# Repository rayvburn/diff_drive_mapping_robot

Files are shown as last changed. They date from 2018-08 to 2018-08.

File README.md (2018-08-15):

# diff_drive_mapping_robot
This is the ROS driver for the Raspberry Pi based differential drive robot that was built as a part of my MSc thesis. 

Base of the robot was made of acrylic glass. The locomotion is provided by 3 wheels, including 1 caster. The two-wheel differential drive based on DC motors makes the machine nonholonomic.

Within the electronic part of the robot's construction, a printed circuit board was designed. All the necessary electronical components including reflective sensors used to measure the distance from obstacles were placed on the board. The sensor providing the largest amount of data is the camera. It is integrated with the Raspberry Pi microcomputer. The extension of the microcomputer's tasks to the reading of wheel positions and motor control allowed to use its resources efficiently and to avoid adding an extra microcontroller.

Looking at the PCB project (made in KiCad) should give you some idea what components to use if you plan to make a copy of it.

The robot is intended to work together with remote machine like PC that performs some more sophisticated duties. It was created to interface with ORB-SLAM2 well.

# Installation instructions

The package contents should be placed and compiled both on PC and on RPi's SD card. It was tested only on ROS Kinetic (running on Ubuntu 16.04).

wiringPi library is needed (http://wiringpi.com/). A script to install it on Raspberry Pi was provided.

raspicam_node (https://github.com/UbiquityRobotics/raspicam_node) is required if you will use Raspberry Pi camera but isn't marked as dependency for the package. If you don't plan to use it, just remove appropriate line in robot/robot_offline .launch file (the one with inclusion of raspicam_node's .launch).

# Usage

If a Raspberry Pi is present within a local Wi-Fi network

    roslaunch diff_drive_mapping_robot robot.launch

or for testing purposes (no RPi)

    roslaunch diff_drive_mapping_robot robot_offline.launch
    
# Notes
I highly recommend acquiring an Ubuntu image adequate for Raspberry Pi (with ROS Kinetic already installed) from here: https://downloads.ubiquityrobotics.com/pi.html

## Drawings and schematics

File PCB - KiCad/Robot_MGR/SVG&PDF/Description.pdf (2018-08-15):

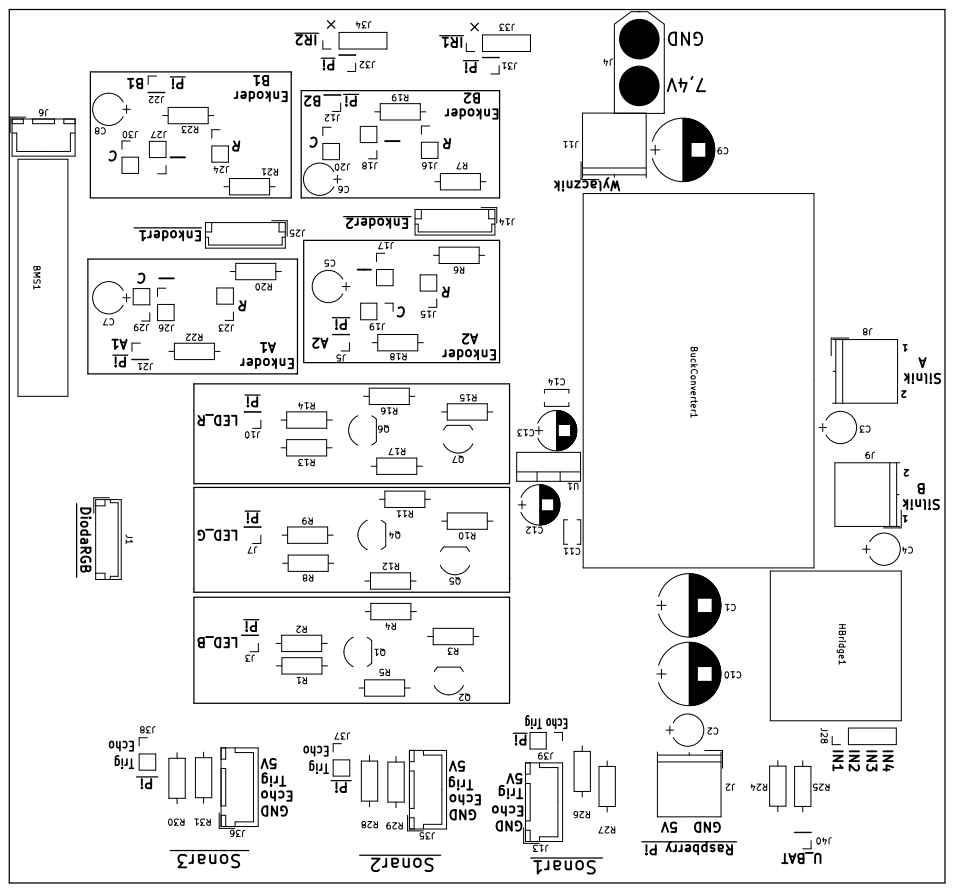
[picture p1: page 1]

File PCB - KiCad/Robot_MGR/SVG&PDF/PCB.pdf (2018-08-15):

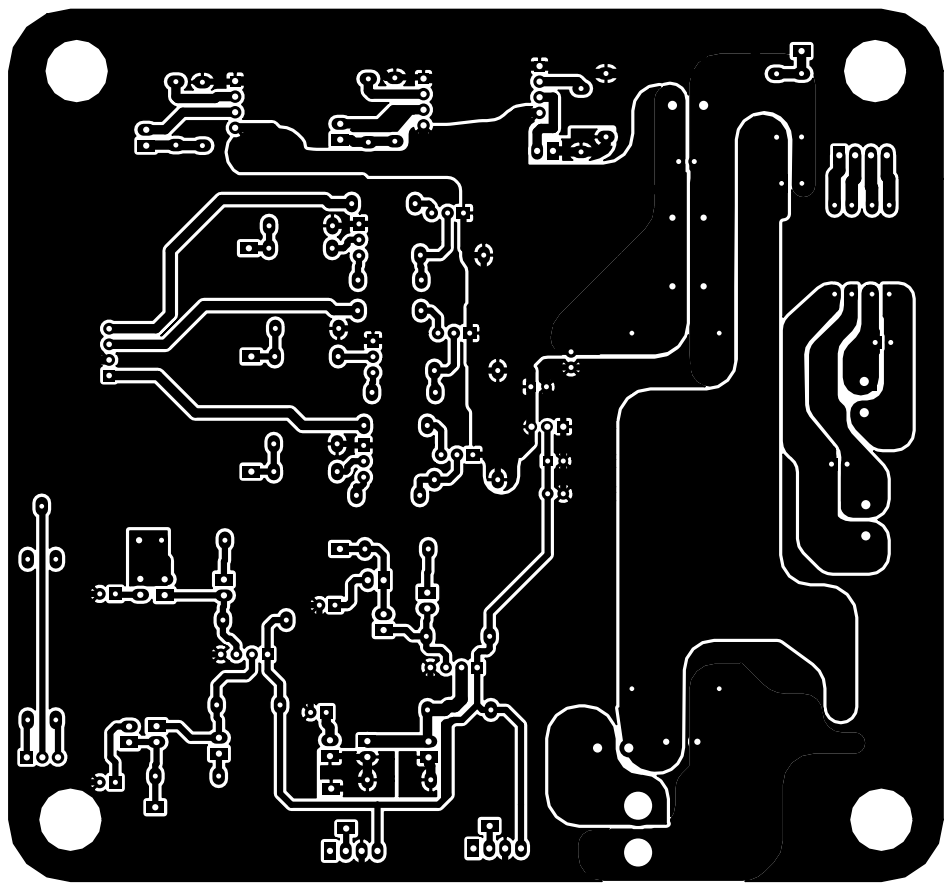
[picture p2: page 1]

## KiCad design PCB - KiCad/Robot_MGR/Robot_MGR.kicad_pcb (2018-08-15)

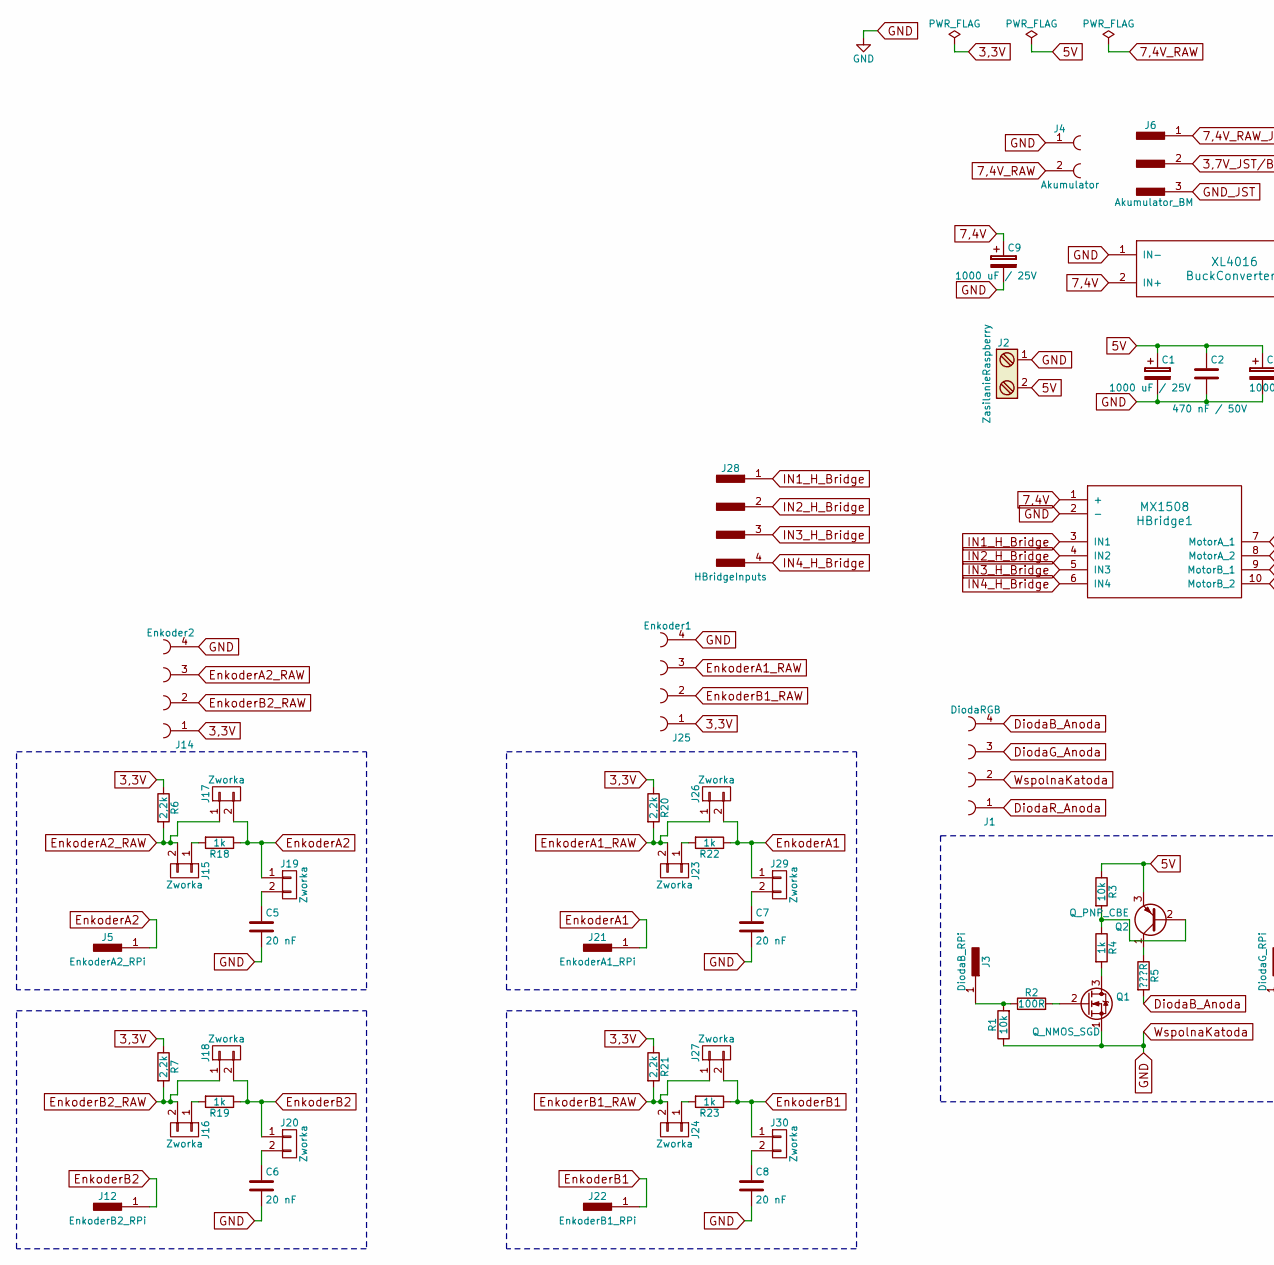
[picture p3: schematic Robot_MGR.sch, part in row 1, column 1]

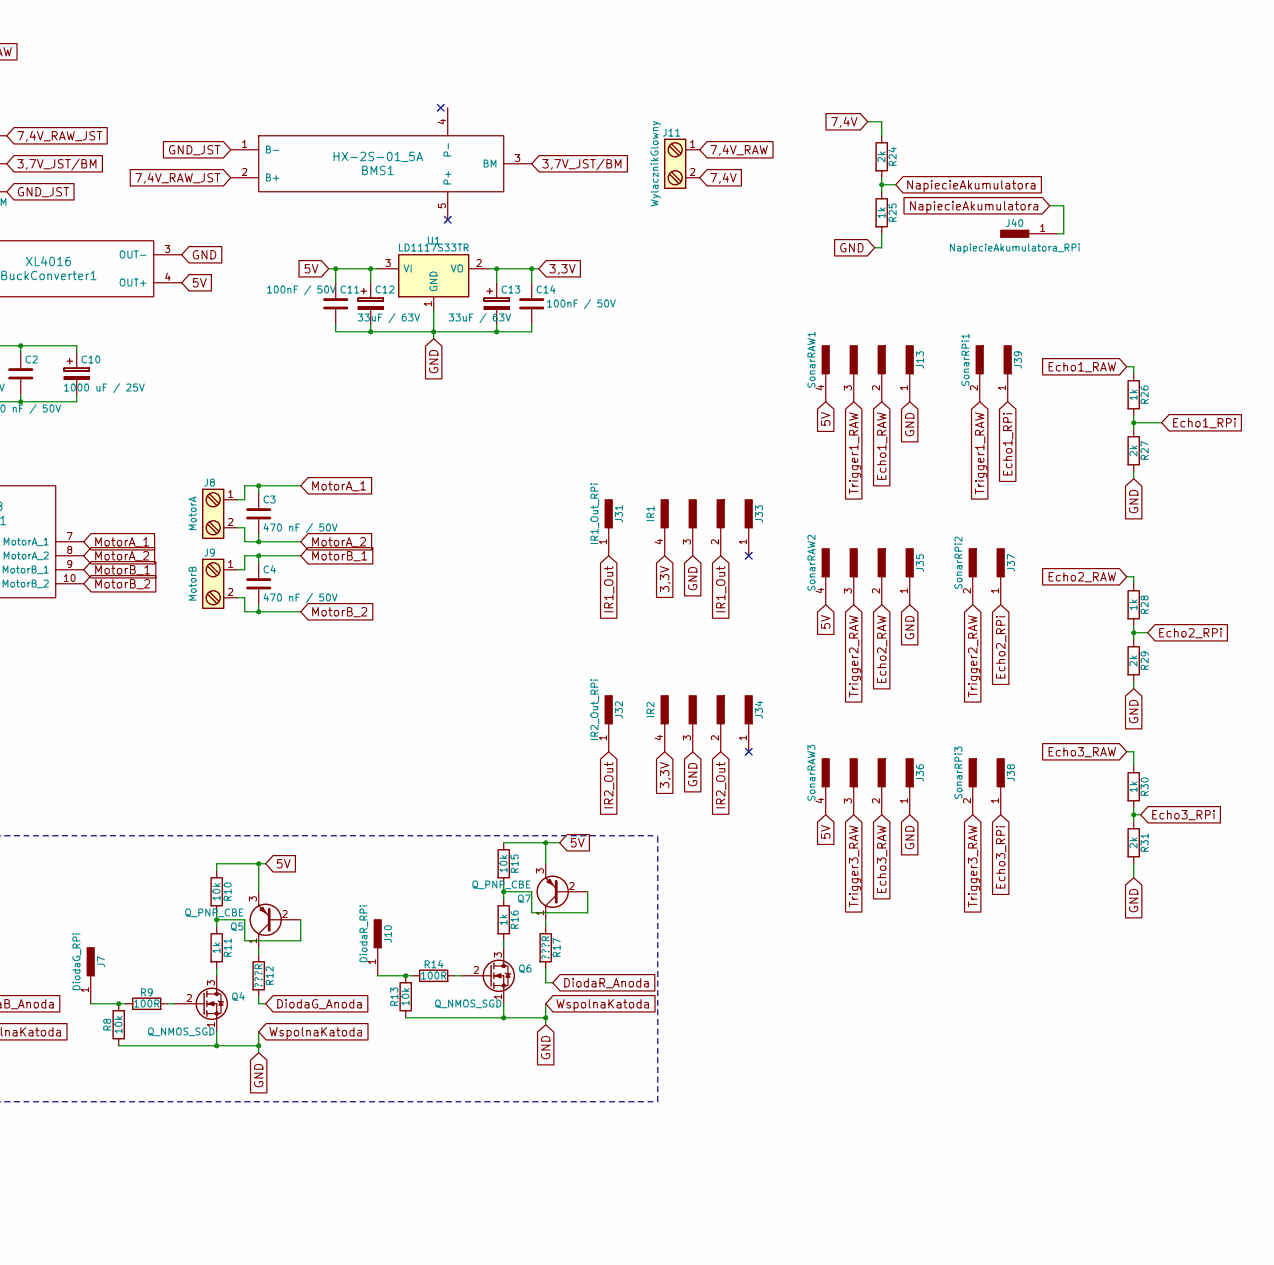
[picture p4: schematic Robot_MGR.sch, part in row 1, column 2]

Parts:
BMS1: HX-2S-01_5A
BuckConverter1: XL4016
C1, C9, C10: 1000 uF / 25V; CP_Radial_D10.0mm_P5.00mm
C2, C3, C4: 470 nF / 50V; CP_Radial_Tantal_D5.0mm_P2.50mm
C5, C6, C7, C8: 20 nF; CP_Radial_Tantal_D5.0mm_P2.50mm
C11, C14: 100nF / 50V; C_Disc_D3.8mm_W2.6mm_P2.50mm
C12, C13: 33uF / 63V; CP_Radial_D6.3mm_P2.50mm
HBridge1: MX1508
J1: DiodaRGB; JST_EH_B04B-EH-A_04x2.50mm_Straight
J2: ZasilanieRaspberry; TerminalBlock_Philmore_TB132_02x5mm_Straight
J3: DiodaB_RPi; Pin_Header_Straight_1x01_Pitch2.54mm
J4: Akumulator; XT60
J5: EnkoderA2_RPi; Pin_Header_Straight_1x01_Pitch2.54mm
J6: Akumulator_BM; JST_XH_B03B-XH-A_03x2.50mm_Straight
J7: DiodaG_RPi; Pin_Header_Straight_1x01_Pitch2.54mm
J8: MotorA; TerminalBlock_Philmore_TB132_02x5mm_Straight
J9: MotorB; TerminalBlock_Philmore_TB132_02x5mm_Straight
J10: DiodaR_RPi; Pin_Header_Straight_1x01_Pitch2.54mm
J11: WylacznikGlowny; TerminalBlock_Philmore_TB132_02x5mm_Straight
J12: EnkoderB2_RPi; Pin_Header_Straight_1x01_Pitch2.54mm
J13: SonarRAW1; JST_XH_B04B-XH-A_04x2.50mm_Straight
J14: Enkoder2; JST_EH_B04B-EH-A_04x2.50mm_Straight
J15, J16, J17, J18, J19, J20, J23, J24, J26, J27, J29, J30: Zworka; Pin_Header_Straight_1x02_Pitch2.54mm
J21: EnkoderA1_RPi; Pin_Header_Straight_1x01_Pitch2.54mm
J22: EnkoderB1_RPi; Pin_Header_Straight_1x01_Pitch2.54mm
J25: Enkoder1; JST_EH_B04B-EH-A_04x2.50mm_Straight
J28: HBridgeInputs; Pin_Header_Straight_1x04_Pitch2.54mm
J31: IR1_Out_RPi; Pin_Header_Straight_1x01_Pitch2.54mm
J32: IR2_Out_RPi; Pin_Header_Straight_1x01_Pitch2.54mm
J33: IR1; Pin_Header_Straight_1x04_Pitch2.54mm
J34: IR2; Pin_Header_Straight_1x04_Pitch2.54mm
J35: SonarRAW2; JST_XH_B04B-XH-A_04x2.50mm_Straight
J36: SonarRAW3; JST_XH_B04B-XH-A_04x2.50mm_Straight
J37: SonarRPi2; Pin_Header_Straight_1x02_Pitch2.54mm
J38: SonarRPi3; Pin_Header_Straight_1x02_Pitch2.54mm
J39: SonarRPi1; Pin_Header_Straight_1x02_Pitch2.54mm
J40: NapiecieAkumulatora_RPi; Pin_Header_Straight_1x01_Pitch2.54mm
Q1, Q4, Q6: Q_NMOS_SGD; TO-92_Inline_Wide
Q2, Q5, Q7: Q_PNP_CBE; TO-92_Inline_Wide
R1, R3, R8, R10, R13, R15: 10k; R_Axial_DIN0207_L6.3mm_D2.5mm_P10.16mm_Horizontal
R2, R9, R14: 100R; R_Axial_DIN0207_L6.3mm_D2.5mm_P10.16mm_Horizontal
R4, R11, R16, R18, R19, R22, R23, R25, R26, R28, R30: 1k; R_Axial_DIN0207_L6.3mm_D2.5mm_P10.16mm_Horizontal
R5, R12, R17: ???R; R_Axial_DIN0207_L6.3mm_D2.5mm_P10.16mm_Horizontal
R6, R7, R20, R21: 2,2k; R_Axial_DIN0207_L6.3mm_D2.5mm_P10.16mm_Horizontal
R24, R27, R29, R31: 2k; R_Axial_DIN0207_L6.3mm_D2.5mm_P10.16mm_Horizontal
U1: LD1117S33TR; TO-220-3_Vertical

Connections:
3,3V: C13.1, C14.1, J14.1, J25.1, J33.4, J34.4, R6.1, R7.1, R20.1, R21.1, U1.2 (VO)
3,7V_JST/BM: BMS1.3 (BM), J6.2
5V: BuckConverter1.4 (OUT+), C1.1, C2.1, C10.1, C11.1, C12.1, J2.2, J13.4, J35.4, J36.4, Q2.3 (E), Q5.3 (E), Q7.3 (E), R3.1, R10.1, R15.1, U1.3 (VI)
7,4V: BuckConverter1.2 (IN+), C9.1, HBridge1.1 (+), J11.2, R24.1
7,4V_RAW: J4.2, J11.1
7,4V_RAW_JST: BMS1.2 (B+), J6.1
DiodaB_Anoda: J1.4, R5.2
DiodaG_Anoda: J1.3, R12.2
DiodaR_Anoda: J1.1, R17.2
Echo1_RAW: J13.2, R26.1
Echo1_RPi: J39.1, R26.2, R27.1
Echo2_RAW: J35.2, R28.1
Echo2_RPi: J37.1, R28.2, R29.1
Echo3_RAW: J36.2, R30.1
Echo3_RPi: J38.1, R30.2, R31.1
EnkoderA1: J21.1, J26.2, J29.1, R22.1
EnkoderA1_RAW: J23.2, J25.3, J26.1, R20.2
EnkoderA2: J5.1, J17.2, J19.1, R18.1
EnkoderA2_RAW: J14.3, J15.2, J17.1, R6.2
EnkoderB1: J22.1, J27.2, J30.1, R23.1
EnkoderB1_RAW: J24.2, J25.2, J27.1, R21.2
EnkoderB2: J12.1, J18.2, J20.1, R19.1
EnkoderB2_RAW: J14.2, J16.2, J18.1, R7.2
GND: BuckConverter1.1 (IN-), BuckConverter1.3 (OUT-), C1.2, C2.2, C5.2, C6.2, C7.2, C8.2, C9.2, C10.2, C11.2, C12.2, C13.2, C14.2, HBridge1.2 (-), J1.2, J2.1, J4.1, J13.1, J14.4, J25.4, J33.3, J34.3, J35.1, J36.1, Q1.1 (S), Q4.1 (S), Q6.1 (S), R1.1, R8.1, R13.1, R25.2, R27.2, R29.2, R31.2, U1.1 (GND)
GND_JST: BMS1.1 (B-), J6.3
IN1_H_Bridge: HBridge1.3 (IN1), J28.1
IN2_H_Bridge: HBridge1.4 (IN2), J28.2
IN3_H_Bridge: HBridge1.5 (IN3), J28.3
IN4_H_Bridge: HBridge1.6 (IN4), J28.4
IR1_Out: J31.1, J33.2
IR2_Out: J32.1, J34.2
MotorA_1: C3.1, HBridge1.7 (MotorA_1), J8.1
MotorA_2: C3.2, HBridge1.8 (MotorA_2), J8.2
MotorB_1: C4.1, HBridge1.9 (MotorB_1), J9.1
MotorB_2: C4.2, HBridge1.10 (MotorB_2), J9.2
NapiecieAkumulatora: J40.1, R24.2, R25.1
unnamed: C5.1, J19.2
unnamed: C6.1, J20.2
unnamed: C7.1, J29.2
unnamed: C8.1, J30.2
unnamed: J3.1, R1.2, R2.1
unnamed: J7.1, R8.2, R9.1
unnamed: J10.1, R13.2, R14.1
unnamed: J15.1, R18.2
unnamed: J16.1, R19.2
unnamed: J23.1, R22.2
unnamed: J24.1, R23.2
unnamed: Q1.2 (G), R2.2
unnamed: Q1.3 (D), R4.2
unnamed: Q2.1 (C), R5.1
unnamed: Q2.2 (B), R3.2, R4.1
unnamed: Q4.2 (G), R9.2
unnamed: Q4.3 (D), R11.2
unnamed: Q5.1 (C), R12.1
unnamed: Q5.2 (B), R10.2, R11.1
unnamed: Q6.2 (G), R14.2
unnamed: Q6.3 (D), R16.2
unnamed: Q7.1 (C), R17.1
unnamed: Q7.2 (B), R15.2, R16.1
Trigger1_RAW: J13.3, J39.2
Trigger2_RAW: J35.3, J37.2
Trigger3_RAW: J36.3, J38.2

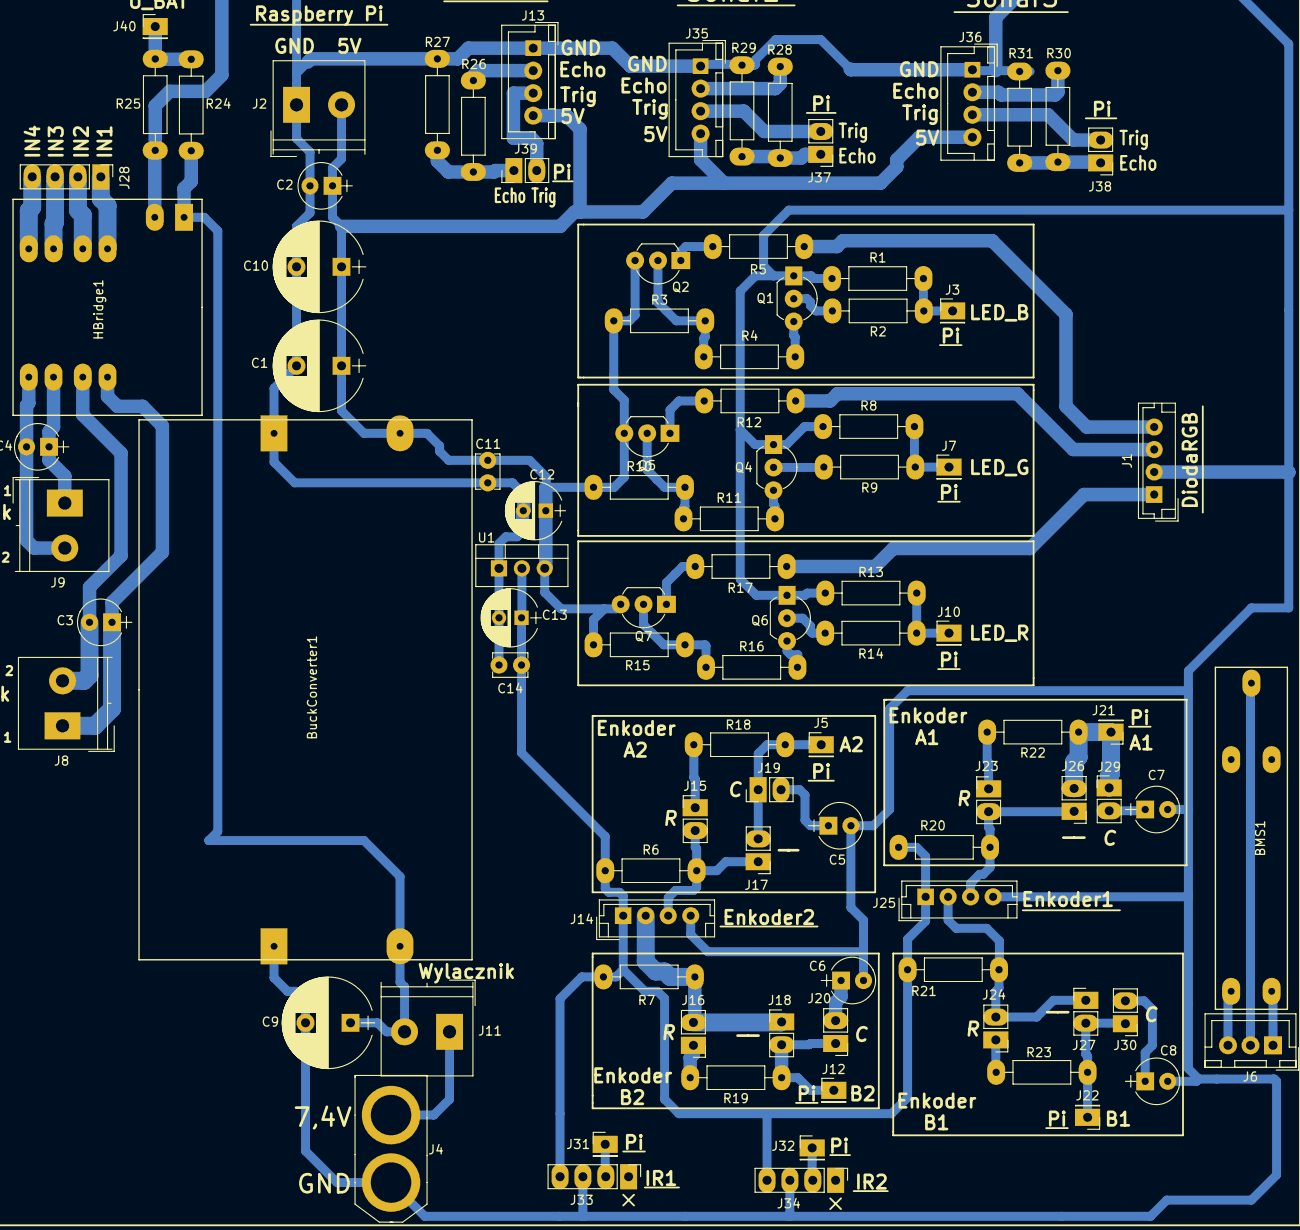
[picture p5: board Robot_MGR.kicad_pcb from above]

Board: 2 copper layers, 95 parts (0 on the bottom side), 62 nets.

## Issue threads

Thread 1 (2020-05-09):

Tuning PID controllers

f-jiang, 2020-05-09:
I'm not sure if this is the right place to be asking, but I have a robot similar to yours with the `diff_drive_controller` and `pid` nodes organized the exact same way. I'm currently at the stage of tuning my PID controllers and wanted to understand the best approach to doing so. Did you tune your PIDs in a simulator, and how did you set things up?

rayvburn, 2020-07-29:
Sorry for a late reply.

Whole testing process was conducted on the real robot. To tune the PID params I used a trial and error method, starting from a set of verified settings from some example.

Closed 2020-07-29.

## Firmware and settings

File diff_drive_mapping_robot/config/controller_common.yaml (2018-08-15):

mobile_base_controller:
  enable_odom_tf: true
  odom_frame_id: odom
  publish_cmd: true
  angular:
    z: {has_acceleration_limits: true, has_jerk_limits: true, has_velocity_limits: true,
      max_acceleration: 2.5, max_jerk: 5.0, max_velocity: 25.0}
  base_frame_id: base_link
  cmd_vel_timeout: 1.15 # needed to be higher due to some networks lags, was 0.25
  left_wheel: wheel_0_joint
  linear:
    x: {has_acceleration_limits: true, has_jerk_limits: true, has_velocity_limits: true,
      max_acceleration: 1.0, max_jerk: 5.0, max_velocity: 25.0, min_acceleration: -1.0,
      min_velocity: -25.0}
  pose_covariance_diagonal: [0.001, 0.001, 1000000.0, 1000000.0, 1000000.0, 1000.0]
  publish_rate: 25.0 # 100.0
  right_wheel: wheel_1_joint
  twist_covariance_diagonal: [0.001, 0.001, 1000000.0, 1000000.0, 1000000.0, 1000.0]
  type: diff_drive_controller/DiffDriveController
  wheel_radius: 0.03315
  wheel_radius_multiplier: 1.0
  wheel_separation: 0.1655
  wheel_separation_multiplier: 1.0

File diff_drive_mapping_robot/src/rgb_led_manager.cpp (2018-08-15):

/*
 * rgb_led_manager.cpp
 *
 *  Created on: Apr 11, 2018
 *      Author: jarek
 */

#include <ros/ros.h>
#include <ros/callback_queue.h>
#include <softPwm.h>
#include <wiringPi.h>
#include <sensor_msgs/BatteryState.h>
#include <std_msgs/Bool.h>
#include <std_msgs/String.h>

#define LED_RED_PIN             3
#define LED_GREEN_PIN           2
#define LED_BLUE_PIN            0

#define MAX_PWM_VALUE         100
#define SINGLE_LED_PWM_VALUE   20

#define EVENT_DURATION         10

static float intensity_factor;
static float blinking_frequency;

static uint8_t slam_state = 5;     // ORB description
static bool loop_detected = false; // GBA is running
static bool loop_blinking = false; // to prevent switching _detected to false when GBA is finished

// prototypes
void colorsInitialization();
struct RGBColor;
void lightUp(const RGBColor *color);

struct RGBColor {
  RGBColor():  r(0), g(0), b(0) {}
  uint8_t r;
  uint8_t g;
  uint8_t b;
} slam_not_ready, slam_no_img, slam_not_inited, slam_ok, slam_lost, loop_closed, led_off;


void loop_closeCallback(const std_msgs::Bool::ConstPtr &msg) {

  if ( msg->data == true ) {
    loop_detected = true;
  } else {
    loop_detected = false;
  }

}

void slam_stateCallback(const std_msgs::String::ConstPtr &msg) {

  std::string str = std::string(msg->data);
  if (str == "System not ready") {
    slam_state = 0;
  } else if (str == "No images yet") {
    slam_state = 1;
  } else if (str == "Not initialized") {
    slam_state = 2;
  } else if (str == "OK") {
    slam_state = 3;
  } else if (str == "Tracking lost") {
    slam_state = 4;
  } else {
    slam_state = 5;
  }

}

void timerCallback(const ros::TimerEvent& e, ros::Timer &timer_duration) {

  static bool led_state = true; // start with led turned on

  if ( led_state ^= true ) {    // blink

    if ( loop_detected ) {

      loop_blinking = true;
      timer_duration.start();
      lightUp(&loop_closed);

    } else if ( loop_blinking ) {

      lightUp(&loop_closed);

    } else if ( !loop_blinking && !loop_detected ) { // loop detection fully performed

      switch (slam_state) {
        case 0:
            lightUp(&slam_not_ready);
            break;
        case 1:
            lightUp(&slam_no_img);
            break;
        case 2:
            lightUp(&slam_not_inited);
            break;
        case 3:
            lightUp(&slam_ok);
            break;
        case 4:
            lightUp(&slam_lost);
            break;
        case 5:
            lightUp(&led_off);
            break;
      }
    }

  } else {
    lightUp(&led_off);
  }
}

void timer_event_durationCallback(const ros::TimerEvent& e, ros::Timer &timer_duration) {

  if ( loop_blinking ) {
    loop_blinking = false;
    timer_duration.stop();
  }

}

int main(int argc, char** argv)
{

  ros::init(argc, argv, "rgb_led_manager");
  ros::NodeHandle nh;

  colorsInitialization();
  std::string loop_close_topic, slam_state_topic;
  nh.param<std::string>("/robot/rgb_manager/loop_close_topic", loop_close_topic, "/orb_slam2/info/loop_closed");
  nh.param<std::string>("/robot/rgb_manager/slam_state_topic", slam_state_topic, "/orb_slam2/info/state_description");
  nh.param<float>("/robot/rgb_manager/intensity_factor", intensity_factor, 0.10);
  nh.param<float>("/robot/rgb_manager/blinking_frequency", blinking_frequency, 1);

  ros::Subscriber slam_loop_sub = nh.subscribe(loop_close_topic, 1, loop_closeCallback);
  ros::Subscriber slam_state_sub = nh.subscribe(slam_state_topic, 1, slam_stateCallback);

  ros::CallbackQueue tim_queue;
  ros::AsyncSpinner led_spinner(1, &tim_queue);
  ros::Timer timer_blink, timer_duration;
  ros::TimerEvent blink_event, duration_event;

  ros::TimerOptions duration_timer(ros::Duration(EVENT_DURATION),
                                   std::bind(timer_event_durationCallback,
                                             std::ref(duration_event),
                                             std::ref(timer_duration)), // to allow stop inside callback
                                &tim_queue);
  timer_duration = nh.createTimer(duration_timer);

  ros::TimerOptions blinking_timer(ros::Duration(1/blinking_frequency),
                                std::bind(timerCallback,
                                          std::ref(blink_event),
                                          std::ref(timer_duration)),
                                &tim_queue);
  timer_blink = nh.createTimer(blinking_timer);

  wiringPiSetup();
  pinMode(LED_RED_PIN,   OUTPUT);
  pinMode(LED_GREEN_PIN, OUTPUT);
  pinMode(LED_BLUE_PIN,  OUTPUT);

  softPwmCreate(LED_RED_PIN,   0, MAX_PWM_VALUE);
  softPwmCreate(LED_GREEN_PIN, 0, MAX_PWM_VALUE);
  softPwmCreate(LED_BLUE_PIN,  0, MAX_PWM_VALUE);

  led_spinner.start();
  ros::spin();

  lightUp(&led_off);
  return 0;

}

void colorsInitialization() {
  slam_not_ready.r = 204;  slam_not_ready.b = 255;   // purple
  slam_no_img.g = 204;     slam_no_img.b = 255;      // sea
  slam_not_inited.r = 255; slam_not_inited.g = 255;  // yellow
  slam_ok.g = 255;                                   // green
  slam_lost.r = 255;                                 // red
  loop_closed.r = 255;     loop_closed.g = 128;      // orange
}

void lightUp(const RGBColor *color) {

  softPwmWrite(LED_RED_PIN,   intensity_factor*color->r);
  softPwmWrite(LED_GREEN_PIN, intensity_factor*color->g);
  softPwmWrite(LED_BLUE_PIN,  intensity_factor*color->b);

}

/*
 *

ros::Subscriber battery_sub = nh.subscribe("robot/battery_state", 1, battery_stateCallback);

void battery_stateCallback(const sensor_msgs::BatteryState::ConstPtr &msg) {
  // not used at the moment due to lack of embedded ADC in RPi3
  if ( msg->voltage == 0 ) {
    softPwmWrite(LED_RED_PIN,   MAX_PWM_VALUE);
    softPwmWrite(LED_GREEN_PIN, 0);
    softPwmWrite(LED_BLUE_PIN,  0);
    batteryLow = true;
  } else {
    softPwmWrite(LED_RED_PIN,   0);
    softPwmWrite(LED_GREEN_PIN, SINGLE_LED_PWM_VALUE);
    softPwmWrite(LED_BLUE_PIN,  0);
    batteryLow = false;
  }
}
*/

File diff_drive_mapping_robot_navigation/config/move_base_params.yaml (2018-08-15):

# ============ Move base node parameters =======
# == http://wiki.ros.org/move_base#Parameters ==

# global planner - http://wiki.ros.org/nav_core#BaseGlobalPlanner
base_global_planner: "navfn/NavfnROS"

# local planner - http://wiki.ros.org/nav_core#BaseLocalPlanner
base_local_planner: "dwa_local_planner/DWAPlannerROS"

# A list of recovery behavior plugins to use with move_base
recovery_behaviors: 
     - {name: conservative_reset, type: clear_costmap_recovery/ClearCostmapRecovery}
     - {name: rotate_recovery,    type: rotate_recovery/RotateRecovery }
#     - {name: move_slow,          type: move_slow_and_clear/MoveSlowAndClear }

# cntr_frq = The rate in Hz at which to run the control loop and send velocity
# commands to the base. controller_frequency: 10.0    # 5.0 ## SEEMS NOT TO 
# WORK FROM THIS FILE (LOCAL PLANNER ALSO HAS THIS)
controller_frequency: 10.0

# How long the planner will wait in seconds in an attempt to find a
# valid plan before space-clearing operations are performed.
planner_patience: 8.0

# How long the controller will wait in seconds without receiving a
# valid control before space-clearing operations are performed.
controller_patience: 10.0 # def 3, was 15.0

# The distance away from the robot in meters at which obstacles will 
# be cleared from the costmap when attempting to clear space in the map
# Works only with default recovery behavior.
conservative_reset_dist: 0.5

# Enables the move_base recovery behaviors to attempt to clear out space.
recovery_behavior_enabled: true

# Robot will attempt an in-place rotation when attempting to clear out 
# space. Works only with default recovery behavior.
clearing_rotation_allowed: true

# Determines whether or not to shutdown the costmaps of the node when
# move_base is in an inactive state
shutdown_costmaps: false

# How long in seconds to allow for oscillation before executing
# recovery behaviors. A value of 0.0 corresponds to an infinite timeout.
oscillation_timeout: 10.0 # 30.0 # 10.0

# How far in meters the robot must move to be considered not to be
# oscillating. Moving this far resets the timer counting up to the
# ~oscillation_timeout # oscillation_distance: 0.2
oscillation_distance: 0.05

# The rate in Hz at which to run the global planning loop. If the
# frequency is set to 0.0, the global planner will only run when a new
# goal is received or the local planner reports that its path is
# blocked.
planner_frequency: 0.0

# How many times to allow for planning retries before executing recovery # behaviors. -1 corresponds to an infinite retries.
max_planning_retries: 100

# recovery_behaviors parameters
conservative_reset:
  reset_distance: 0.5   # The radius away from the robot in meters outside which obstacles will be removed from the costmaps
  layer_names: sonar
rotate_recovery:
  sim_granularity: 0.02 # The distance in radians between checks for obstacles when checking if an in-place rotation is safe
move_slow:
  limited_trans_speed: 0.02
  limited_rot_speed: 0.15
  limited_distance: 0.25

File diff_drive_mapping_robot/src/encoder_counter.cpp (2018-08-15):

#include <ros/ros.h>
#include <std_msgs/Float64.h>
#include <wiringPi.h>
#include <stdint.h>

#define ENCODER_A_PHASE_A  1
#define ENCODER_A_PHASE_B  4
#define ENCODER_B_PHASE_A  6
#define ENCODER_B_PHASE_B  5

#define PULSES_PER_REV     243
#define ANGLE_INCREMENT    0.02585673  // 2pi / 243

volatile static long right_wheel_ticks = 0;
volatile static long  left_wheel_ticks = 0;

volatile static uint8_t right_fwd_tick_count = 1;
volatile static uint8_t  left_fwd_tick_count = 1;
volatile static uint8_t right_bwd_tick_count = 1;
volatile static uint8_t  left_bwd_tick_count = 1;

/*
 * encoder signals interpreted as in:
 *  http://www.dynapar.com/Technology/Encoder_Basics/Quadrature_Encoder/
 */

void encoder_a_ISR() {

  if ( digitalRead(ENCODER_A_PHASE_A) == 1 ) {

    if ( digitalRead(ENCODER_A_PHASE_B) == 0 ) {
      right_fwd_tick_count = 1;
      right_bwd_tick_count = 0;
    } else {
      right_fwd_tick_count = 0;
      right_bwd_tick_count = 1;
    }

  } else {

    // temporary changed from increment to decrement and vice-versa
    // TODO: remake logic
    if ( digitalRead(ENCODER_A_PHASE_B) == 1 ) {
      if ( right_fwd_tick_count == 1 ) {
        right_wheel_ticks--;
        right_fwd_tick_count = 0;
      }
    } else {
      if ( right_bwd_tick_count == 1 ) {
        right_wheel_ticks++;
        right_bwd_tick_count = 0;
      }
    }

  }

}

void encoder_b_ISR() {

  if ( digitalRead(ENCODER_B_PHASE_A) == 1 ) {

    if ( digitalRead(ENCODER_B_PHASE_B) == 0 ) {
      left_fwd_tick_count = 1;
      left_bwd_tick_count = 0;
    } else {
      left_fwd_tick_count = 0;
      left_bwd_tick_count = 1;
    }

  } else {

    if ( digitalRead(ENCODER_B_PHASE_B) == 1 ) {
      if ( left_fwd_tick_count == 1 ) {
        left_wheel_ticks++;
        left_fwd_tick_count = 0;
      }
    } else {
      if ( left_bwd_tick_count == 1 ) {
        left_wheel_ticks--;
        left_bwd_tick_count = 0;
      }
    }

  }
}



int main(int argc, char** argv)
{
  ros::init(argc, argv, "encoder_counter");
  ros::NodeHandle nh;
  ros::Publisher l_wheel_pub = nh.advertise<std_msgs::Float64>("robot/wheel_left/encoder",  250);
  ros::Publisher r_wheel_pub = nh.advertise<std_msgs::Float64>("robot/wheel_right/encoder", 250);
  ros::Rate loop_rate(250);

  wiringPiSetup();
  pinMode(ENCODER_A_PHASE_A, INPUT);
  pinMode(ENCODER_A_PHASE_B, INPUT);

  pinMode(ENCODER_B_PHASE_A, INPUT);
  pinMode(ENCODER_B_PHASE_B, INPUT);

  wiringPiISR(ENCODER_A_PHASE_A, INT_EDGE_BOTH, &encoder_a_ISR);
  wiringPiISR(ENCODER_B_PHASE_A, INT_EDGE_BOTH, &encoder_b_ISR);


  while (ros::ok())
  {
    std_msgs::Float64 msg;

    msg.data = left_wheel_ticks * ANGLE_INCREMENT;
    l_wheel_pub.publish(msg);

    msg.data = right_wheel_ticks * ANGLE_INCREMENT;
    r_wheel_pub.publish(msg);

    ros::spinOnce();
    loop_rate.sleep();
  }
}

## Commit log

2018-08-15 Add files via upload
    v0.9.0 - TODO: reading battery voltage by an external ADC
    [controller_common.yaml, controller_params.yaml, diff_drive_robot.urdf]
2018-08-15 Add files via upload
    schematic and PCB design
    [Robot_MGR.kicad_pcb, Robot_MGR.sch]
